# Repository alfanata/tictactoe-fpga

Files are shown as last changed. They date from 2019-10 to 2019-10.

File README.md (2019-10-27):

# Tic Tac Toe game for ice40 FPGA (HX8K)

* Simple tic-tac-toe game for the HX8K FPGA breakout board.

* Can both be played against AI or with 2 human players by setting a switch.

* The AI is based on generating the gametree using the python script and then storing all moves in the BRAM of the FPGA as a ROM. The python script generates the entire BRAM block initialization code.

* A PCB design is also provided that can plug directly into the HX8K breakout board. 

* To support other FPGA's you will have to modify the tictactoe_ram entity to fit other native BRAM types.

<p align="center">
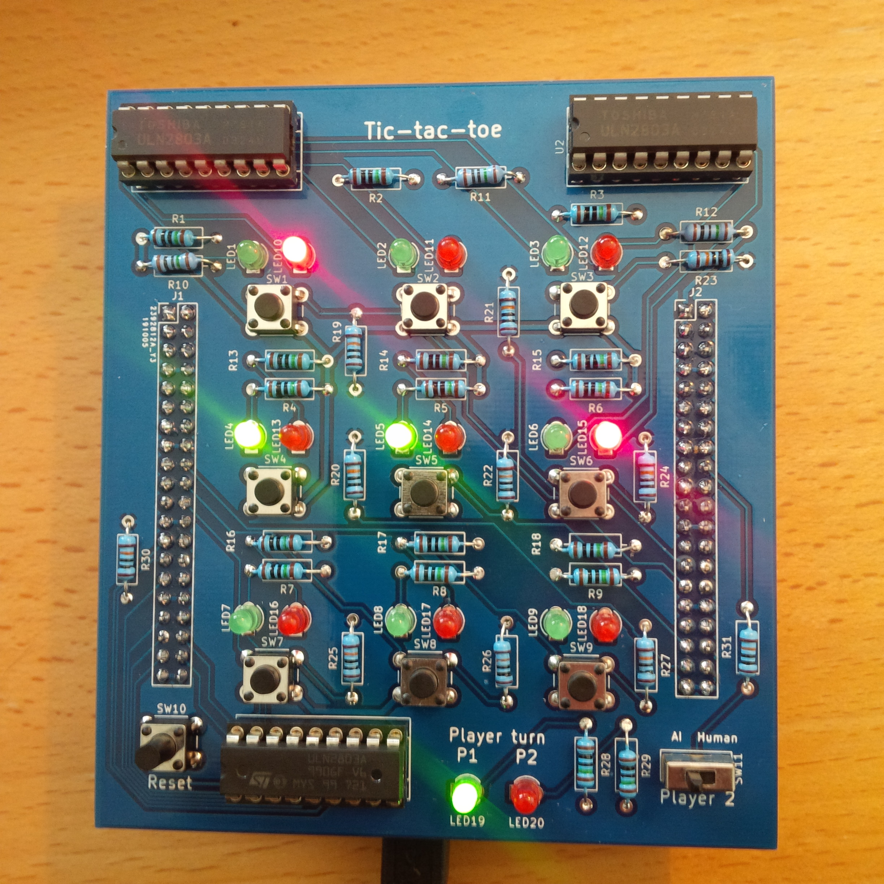
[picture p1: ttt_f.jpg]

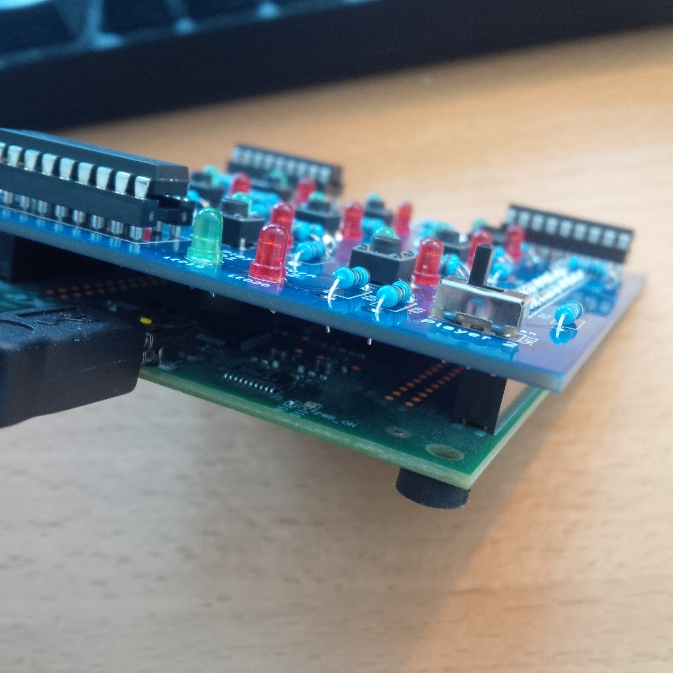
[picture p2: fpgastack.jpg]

</p>

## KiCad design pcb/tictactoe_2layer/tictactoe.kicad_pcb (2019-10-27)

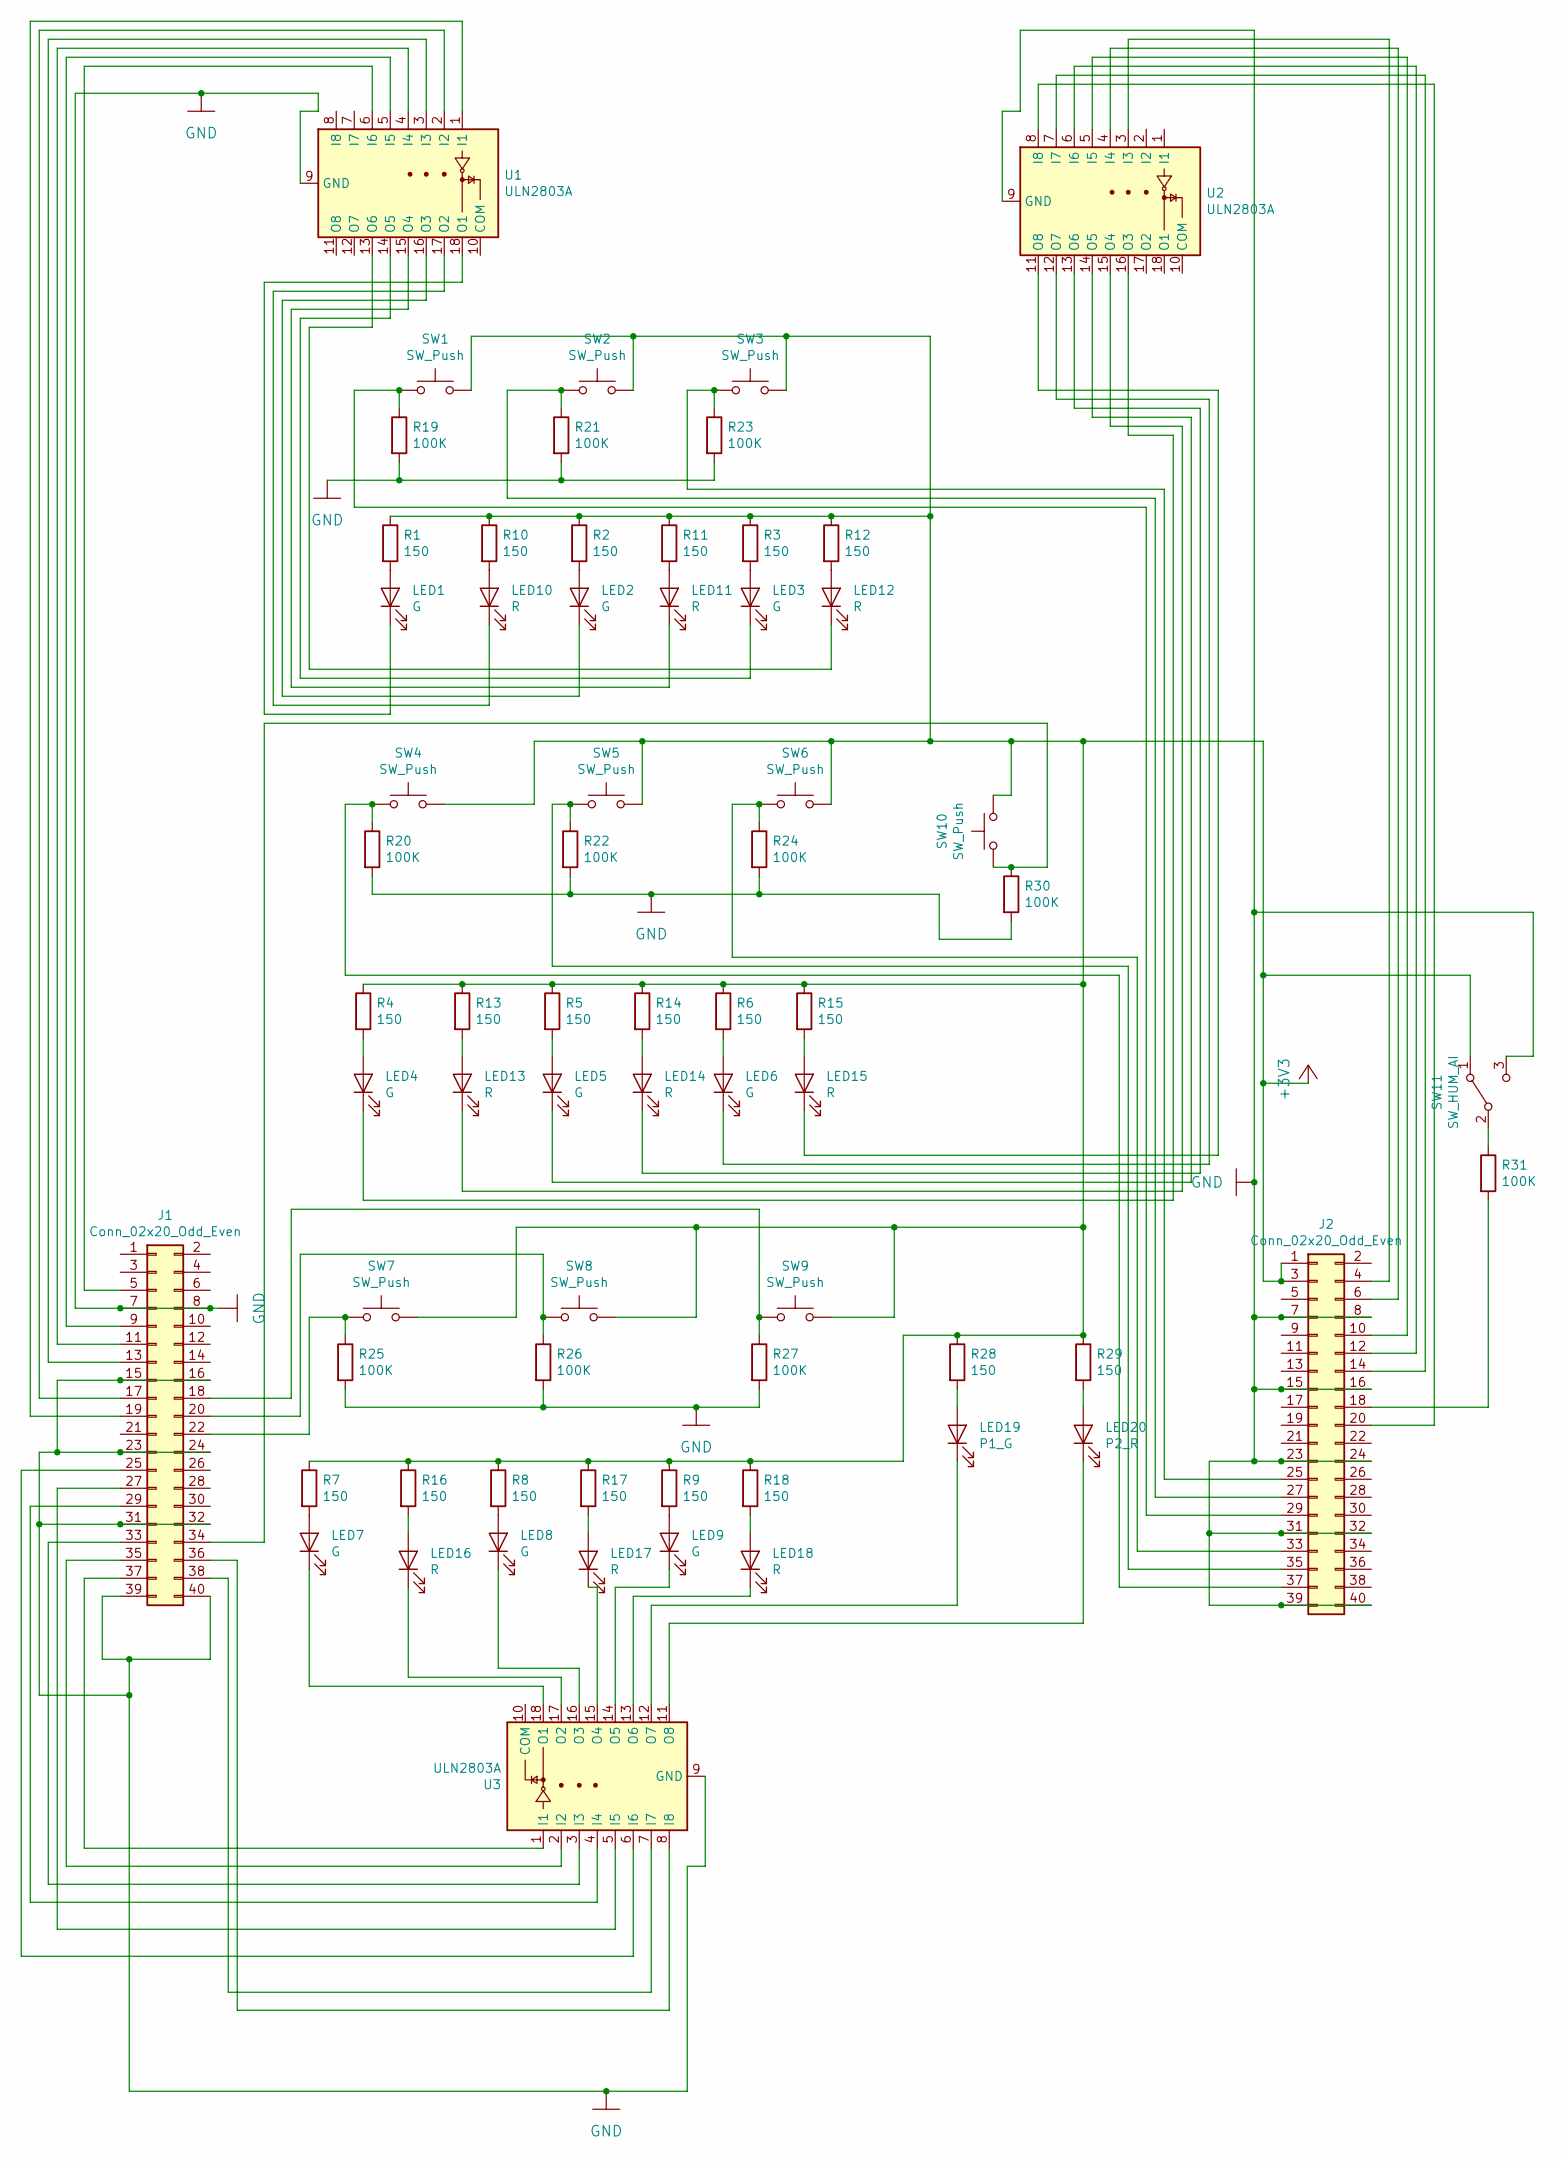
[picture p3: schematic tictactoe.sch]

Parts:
J1, J2: Conn_02x20_Odd_Even; PinHeader_2x20_P2.54mm_Vertical
LED1, LED2, LED3, LED4, LED5, LED6, LED7, LED8, LED9: G; LED_D3.0mm
LED10, LED11, LED12, LED13, LED14, LED15, LED16, LED17, LED18: R; LED_D3.0mm
LED19: P1_G; LED_D3.0mm
LED20: P2_R; LED_D3.0mm
R1, R2, R3, R4, R5, R6, R7, R8, R9, R10, R11, R12, R13, R14, R15, R16, R17, R18, R28, R29: 150; R_Axial_DIN0207_L6.3mm_D2.5mm_P10.16mm_Horizontal
R19, R20, R21, R22, R23, R24, R25, R26, R27, R30, R31: 100K; R_Axial_DIN0207_L6.3mm_D2.5mm_P10.16mm_Horizontal
SW1, SW2, SW3, SW4, SW5, SW6, SW7, SW8, SW9, SW10: SW_Push; SW_PUSH_6mm
SW11: SW_HUM_AI; SS12D00
U1, U2, U3: ULN2803A; DIP-18_W7.62mm_Socket

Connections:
+3V3: J2.1, J2.3, R1.1, R2.1, R3.1, R4.1, R5.1, R6.1, R7.1, R8.1, R9.1, R10.1, R11.1, R12.1, R13.1, R14.1, R15.1, R16.1, R17.1, R18.1, R28.1, R29.1, SW1.2, SW2.2, SW3.2, SW4.2, SW5.2, SW6.2, SW7.2, SW8.2, SW9.2, SW10.2, SW11.1 (A)
GND: J1.7, J1.8, J1.15, J1.16, J1.23, J1.24, J1.31, J1.32, J1.39, J1.40, J2.7, J2.8, J2.15, J2.16, J2.23, J2.24, J2.31, J2.32, J2.39, J2.40, R19.2, R20.2, R21.2, R22.2, R23.2, R24.2, R25.2, R26.2, R27.2, R30.2, SW11.3 (C), U1.9 (GND), U2.9 (GND), U3.9 (GND)
unnamed: J1.5, U1.6 (I6)
unnamed: J1.9, U1.5 (I5)
unnamed: J1.11, U1.4 (I4)
unnamed: J1.13, U1.3 (I3)
unnamed: J1.17, U1.2 (I2)
unnamed: J1.18, R27.1, SW9.1
unnamed: J1.19, U1.1 (I1)
unnamed: J1.20, R26.1, SW8.1
unnamed: J1.22, R25.1, SW7.1
unnamed: J1.25, U3.6 (I6)
unnamed: J1.27, U3.5 (I5)
unnamed: J1.29, U3.4 (I4)
unnamed: J1.33, U3.3 (I3)
unnamed: J1.34, R30.1, SW10.1
unnamed: J1.35, U3.2 (I2)
unnamed: J1.36, U3.8 (I8)
unnamed: J1.37, U3.1 (I1)
unnamed: J1.38, U3.7 (I7)
unnamed: J2.4, U2.3 (I3)
unnamed: J2.6, U2.4 (I4)
unnamed: J2.10, U2.5 (I5)
unnamed: J2.12, U2.6 (I6)
unnamed: J2.14, U2.7 (I7)
unnamed: J2.18, R31.2
unnamed: J2.20, U2.8 (I8)
unnamed: J2.25, R23.1, SW3.1
unnamed: J2.27, R21.1, SW2.1
unnamed: J2.29, R19.1, SW1.1
unnamed: J2.33, R24.1, SW6.1
unnamed: J2.35, R22.1, SW5.1
unnamed: J2.37, R20.1, SW4.1
unnamed: LED1.1 (K), U1.18 (O1)
unnamed: LED1.2 (A), R1.2
unnamed: LED2.1 (K), U1.16 (O3)
unnamed: LED2.2 (A), R2.2
unnamed: LED3.1 (K), U1.14 (O5)
unnamed: LED3.2 (A), R3.2
unnamed: LED4.1 (K), U2.16 (O3)
unnamed: LED4.2 (A), R4.2
unnamed: LED5.1 (K), U2.14 (O5)
unnamed: LED5.2 (A), R5.2
unnamed: LED6.1 (K), U2.12 (O7)
unnamed: LED6.2 (A), R6.2
unnamed: LED7.1 (K), U3.18 (O1)
unnamed: LED7.2 (A), R7.2
unnamed: LED8.1 (K), U3.16 (O3)
unnamed: LED8.2 (A), R8.2
unnamed: LED9.1 (K), U3.14 (O5)
unnamed: LED9.2 (A), R9.2
unnamed: LED10.1 (K), U1.17 (O2)
unnamed: LED10.2 (A), R10.2
unnamed: LED11.1 (K), U1.15 (O4)
unnamed: LED11.2 (A), R11.2
unnamed: LED12.1 (K), U1.13 (O6)
unnamed: LED12.2 (A), R12.2
unnamed: LED13.1 (K), U2.15 (O4)
unnamed: LED13.2 (A), R13.2
unnamed: LED14.1 (K), U2.13 (O6)
unnamed: LED14.2 (A), R14.2
unnamed: LED15.1 (K), U2.11 (O8)
unnamed: LED15.2 (A), R15.2
unnamed: LED16.1 (K), U3.17 (O2)
unnamed: LED16.2 (A), R16.2
unnamed: LED17.1 (K), U3.15 (O4)
unnamed: LED17.2 (A), R17.2
unnamed: LED18.1 (K), U3.13 (O6)
unnamed: LED18.2 (A), R18.2
unnamed: LED19.1 (K), U3.12 (O7)
unnamed: LED19.2 (A), R28.2
unnamed: LED20.1 (K), U3.11 (O8)
unnamed: LED20.2 (A), R29.2
unnamed: R31.1, SW11.2 (B)

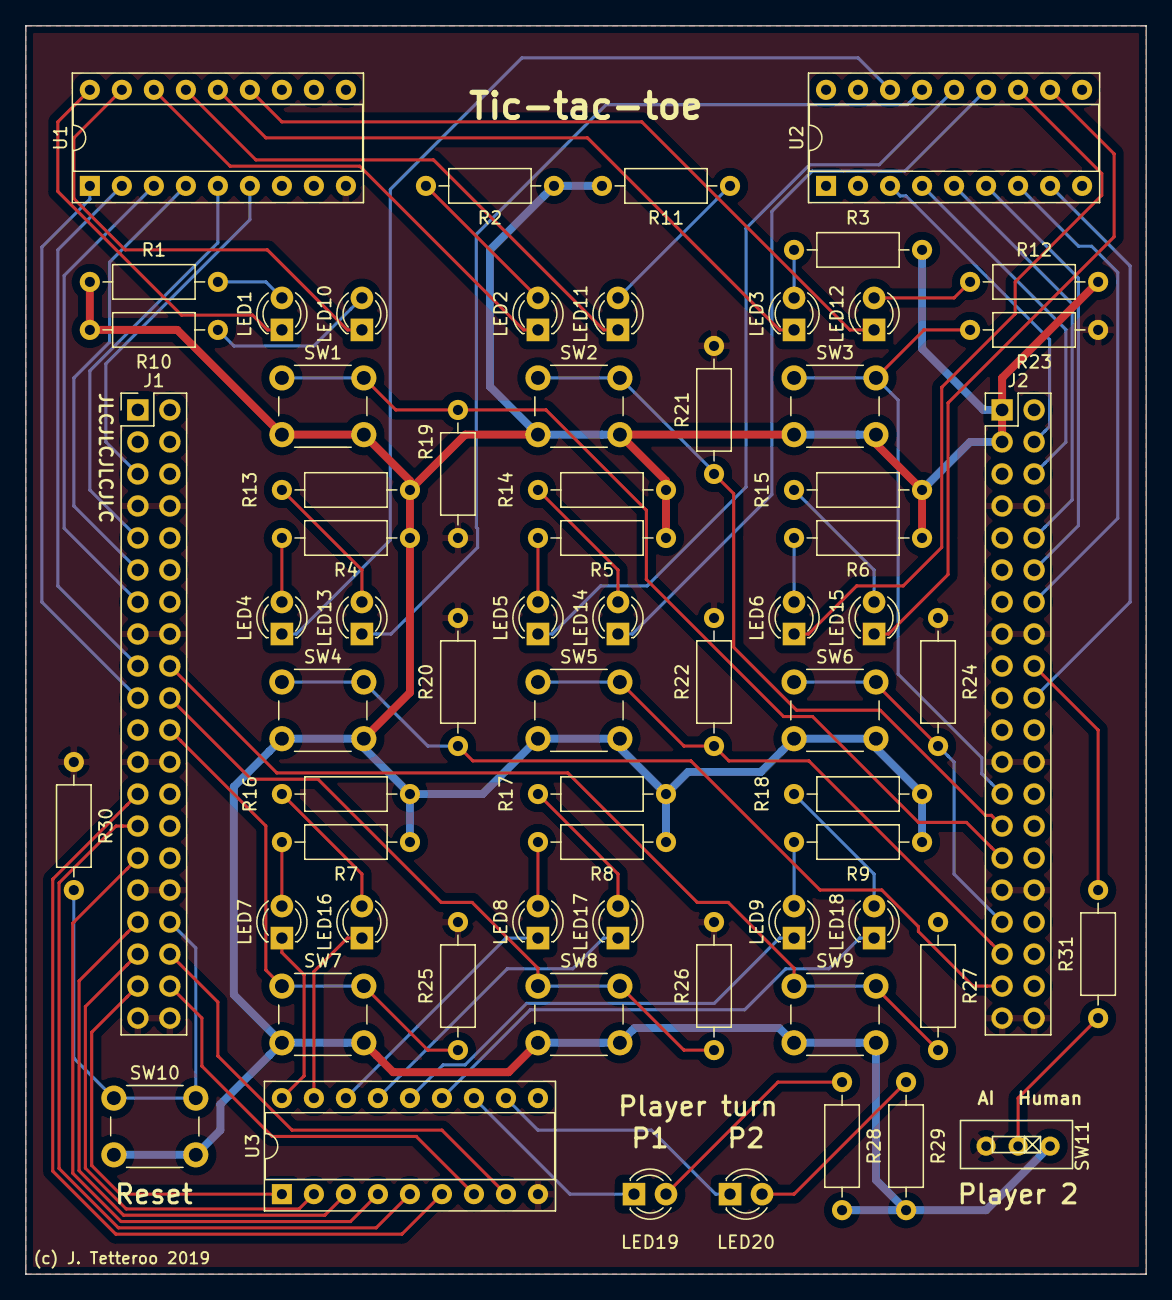
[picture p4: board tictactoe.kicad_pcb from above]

Board: 2 copper layers, 88.9 x 99.1 mm, 67 parts (0 on the bottom side), 74 nets.
